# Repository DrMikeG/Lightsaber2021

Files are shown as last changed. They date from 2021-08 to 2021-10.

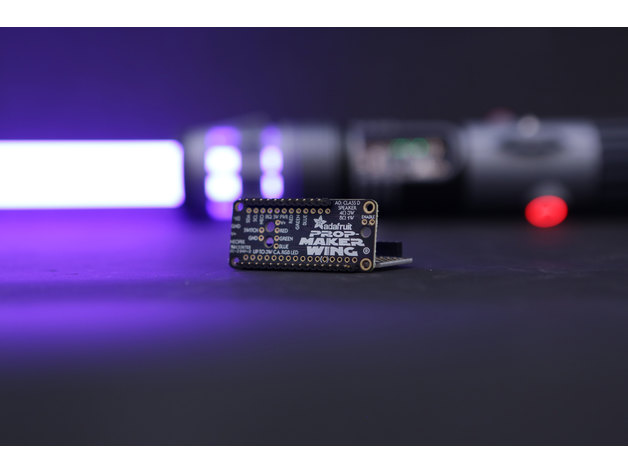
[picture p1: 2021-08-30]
PropMaker_LightSaber_parts/images/3bf46de2e516124390ac1d315bded442_preview_featured.jpg

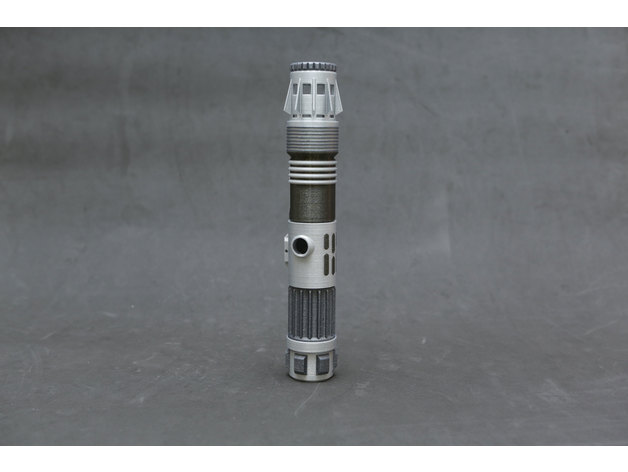
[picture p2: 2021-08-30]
PropMaker_LightSaber_parts/images/14ee97de2baf4f8e66ba40d05824f634_preview_featured.jpg

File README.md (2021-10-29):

# Lightsaber2021
Working on some light sabers with my kids

See: https://youtu.be/GwyaHJhU9TE

I'm using a Adafruit Feather M4 Express - Featuring ATSAMD51 (ATSAMD51 Cortex M4) × 1
which I am programming in circuit python using MU editor.
(You have to turn on the enable switch to get the feather to appear as a drive)
You don't have to turn it on to charge it.

https://learn.adafruit.com/adafruit-prop-maker-featherwing

https://learn.adafruit.com/lightsaber-featherwing

The PWR Pin
As mention above, the PWR pin is low (off) by default. To turn on power to the NeoPixels, Audio output, and RGB LED output, you must set this pin high (on).

You can check the pinout for your Feather to figure out which pin to use. But here's a quick reference for some of the boards:

Feather M0/M4 = D10
Feather 32u4 = D10
Feather 328 = D10
Feather NRF52 = D11
Feather ESP8266 = D15
Feather ESP32 = D33
And be sure to checkout the examples to see how this is done in code.

RGB LED version
https://learn.adafruit.com/prop-maker-light-wand

https://circuitpython.org/board/feather_m4_express/

https://learn.adafruit.com/adafruit-feather-m0-express-designed-for-circuit-python-circuitpython/adafruit2-pinouts

Putting a potentiometer onto an feather m4 express - via the feather prop wing.

The prop wing has breakouts for the express gpio pins, but which analog in pin can I use?

https://learn.adafruit.com/adafruit-prop-maker-featherwing/pinouts

I'm going to name the sides of the boards short and long.
One side of the feather has 16 pins (long) which include analog inputs.
The other side has 12 pins (mostly digital)

The longer side is the one I am interested in.

###Logic###
Only A0 is noted as being used.
```A0 - This pin is true analog input to the audio amplifier on the FeatherWing. Matches A0 on the Feather M0's and M4's which is the DAC output. Other Feathers (like the ESP8266) don't have a DAC so you can leave this pin unused```

###Power###
First two pins 
``Reset pin - Tie to ground to reset the Feather``
``3.3V pin- 3.3V output from the Feather's regulator``

A1 is located along the edge opposite the battery connector. There are multiple ground pins. 3V is located along the same edge as A1, and is next to the reset button.

```
"""CircuitPython Essentials Analog In example"""
import time
import board
from analogio import AnalogIn

analog_in = AnalogIn(board.A1)

def get_voltage(pin):
    return (pin.value * 3.3) / 65536

while True:
    print((get_voltage(analog_in),))
    time.sleep(0.1)
```

![Alt text](./readme_imgs/circuitpython_FeatherM0ExpressPot_bb.jpg)

So, today I learned that the switching tying the enable and ground pins on the prop wing, is an off-on switch, not an on-off switch.

That is - switched closed is off, switch open is on.

So, I tied an switched potentiometer onto the pins, so that I could turn the device on - and adjust an input voltage.

However, because the switch on the wing is, to my mind, backwards - the wing is only on when the switch is off - when the potentiometer is at its lowest setting.

![Alt text](./readme_imgs/Push-Pull-Pots.jpg)

The switch is make/break between the middle lug (eg B) and A or C for the push or pull.

I want to wire B/C as normally closed for off.

Potentiometer
pin value ranges from 160 - 65520

## 2021/09/26 Turn off sound ##

https://www.geeksforgeeks.org/time-perf_counter-function-in-python/

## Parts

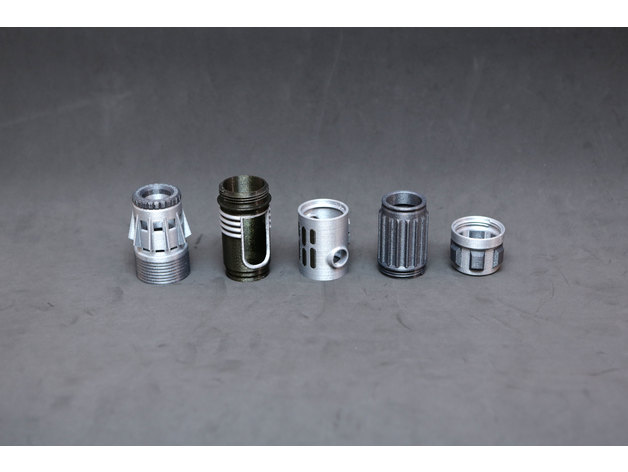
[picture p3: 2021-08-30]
PropMaker_LightSaber_parts/images/43d95a3ca8ac8f66d2d12bcbf307449e_preview_featured.jpg

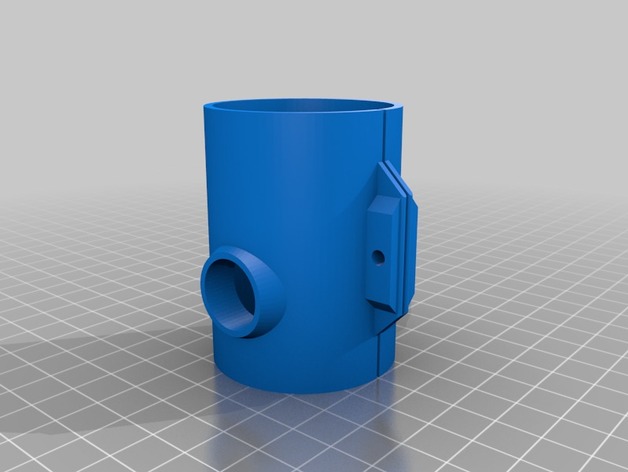
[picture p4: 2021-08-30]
PropMaker_LightSaber_parts/images/2298036a1407b53e1e762833e009448c_preview_featured.jpg

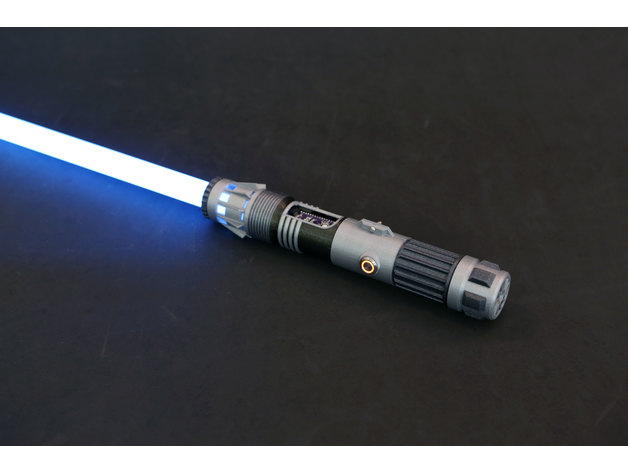
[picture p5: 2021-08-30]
PropMaker_LightSaber_parts/images/57906086d4f9e3c8136e70035f9d3a5d_preview_featured.jpg

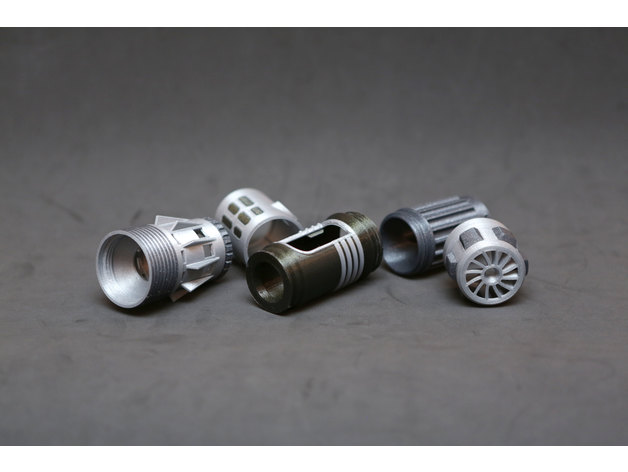
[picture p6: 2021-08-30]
PropMaker_LightSaber_parts/images/89f413c878babc25c42698dab03f24e1_preview_featured.jpg

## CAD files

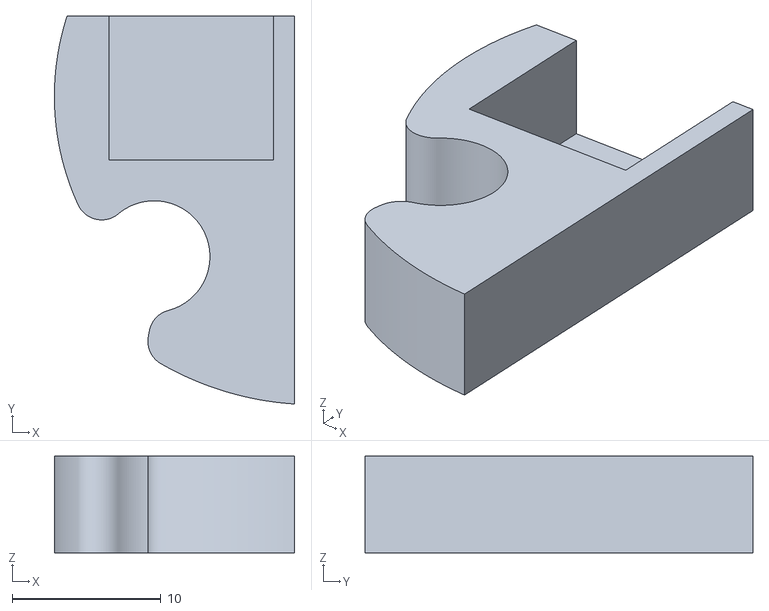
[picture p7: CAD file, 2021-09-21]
parts/UsbSupport01.stl
16.2 x 26.1 x 6.50

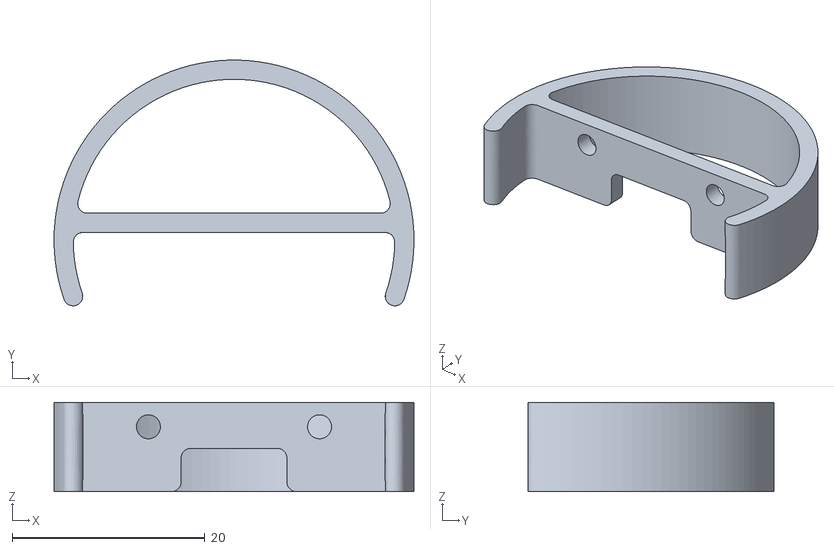
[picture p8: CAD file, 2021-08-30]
PropMaker_LightSaber_parts/files/fwls-feather-mount.stl
37.4 x 25.5 x 9.28

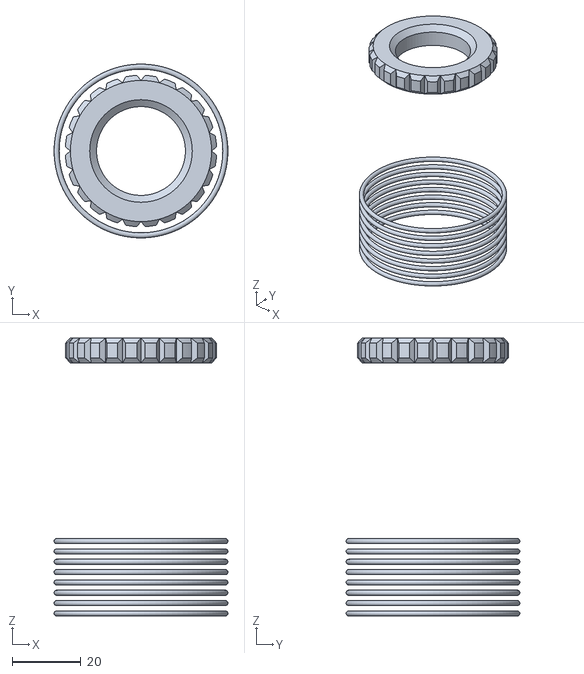
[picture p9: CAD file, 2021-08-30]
PropMaker_LightSaber_parts/files/multimats/fwls-emitter-b.stl
50.5 x 50.5 x 80.8

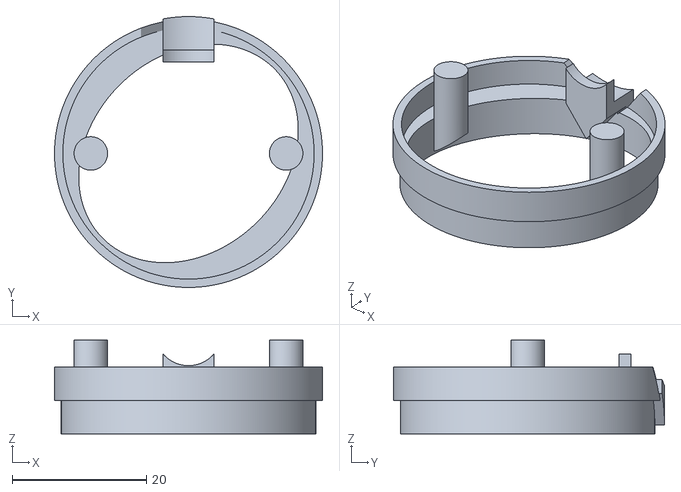
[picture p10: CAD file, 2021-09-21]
parts/BatteryHousing02.stl
40.0 x 40.4 x 14.0

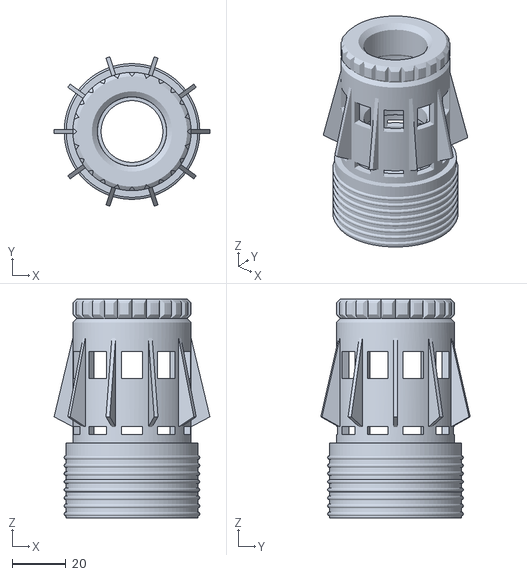
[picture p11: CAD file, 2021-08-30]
PropMaker_LightSaber_parts/files/fwls-emitter-single.stl
58.0 x 55.6 x 81.5

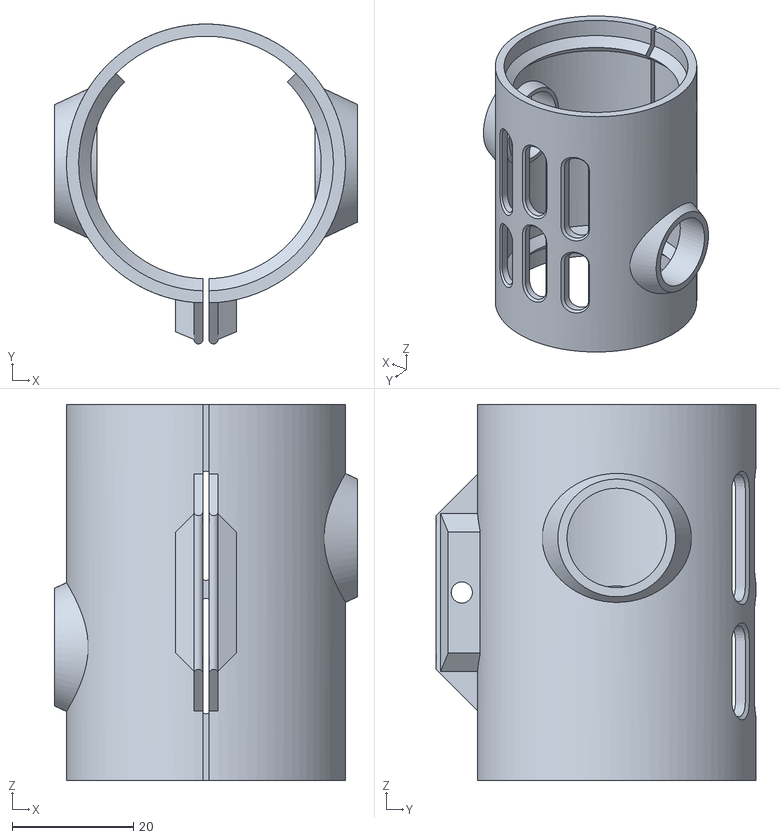
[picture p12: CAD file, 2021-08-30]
PropMaker_LightSaber_parts/files/multimats/fwls-clamp-a.stl
50.0 x 52.8 x 62.0

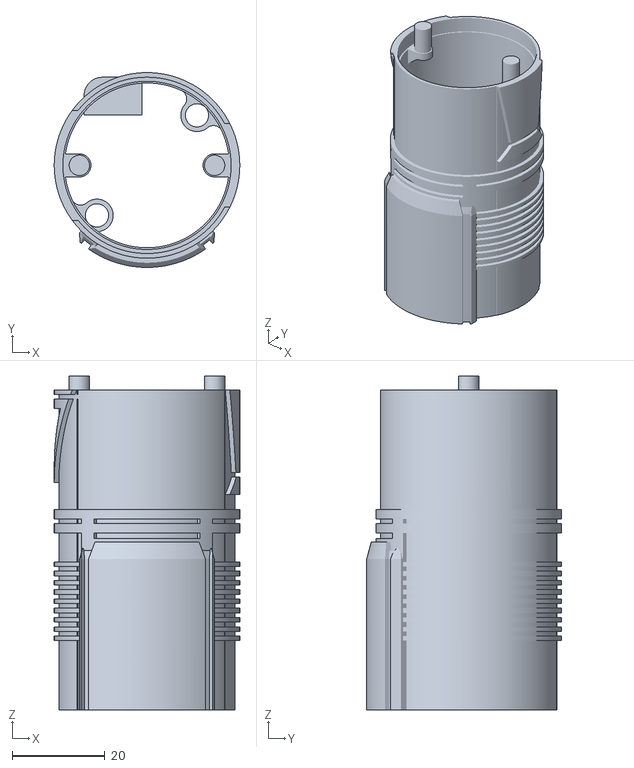
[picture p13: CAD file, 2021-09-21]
parts/FeatherHousing03.stl
40.0 x 42.0 x 72.0

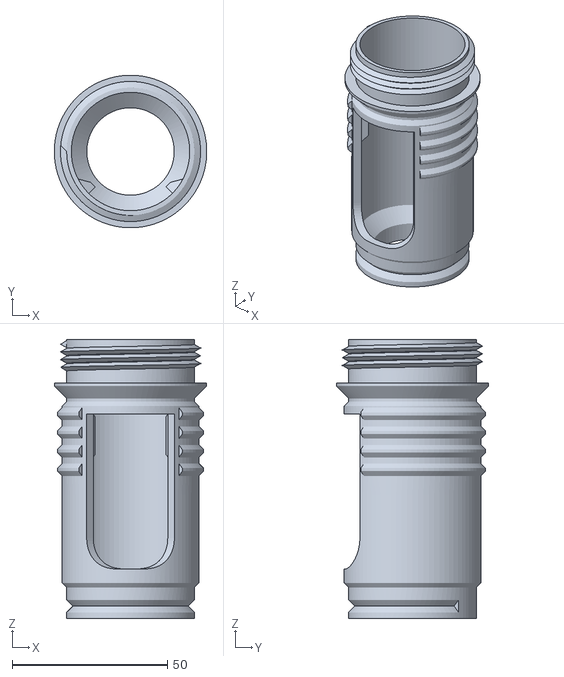
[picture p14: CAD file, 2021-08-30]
PropMaker_LightSaber_parts/files/fwls-barrel-single.stl
49.2 x 49.2 x 90.0

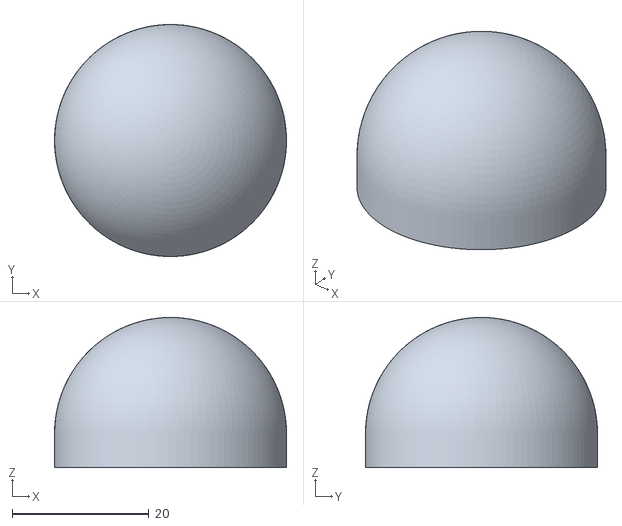
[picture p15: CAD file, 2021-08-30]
PropMaker_LightSaber_parts/files/fwls-blade-cap.stl
34.0 x 34.0 x 22.0

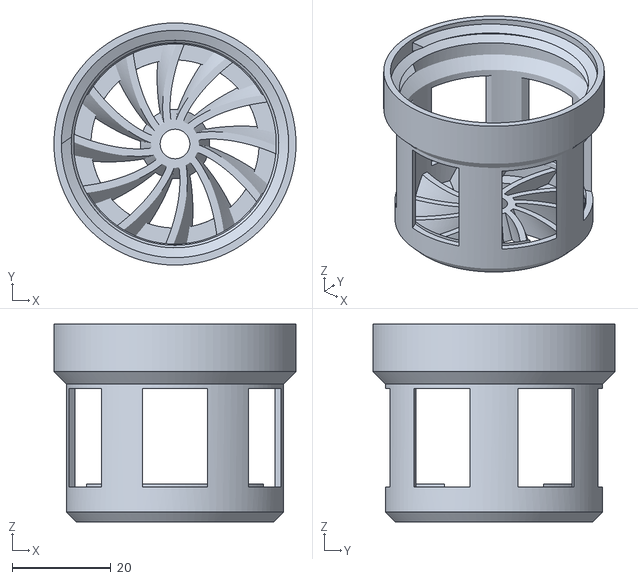
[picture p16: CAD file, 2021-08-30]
PropMaker_LightSaber_parts/files/multimats/fwls-pommel-a.stl
49.0 x 49.0 x 40.0

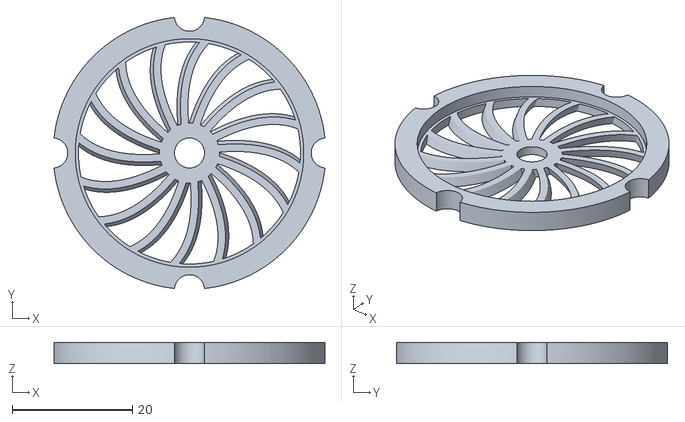
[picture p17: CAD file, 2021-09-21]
parts/SpeakerHousingBottomCover01.stl
45.1 x 45.1 x 3.50

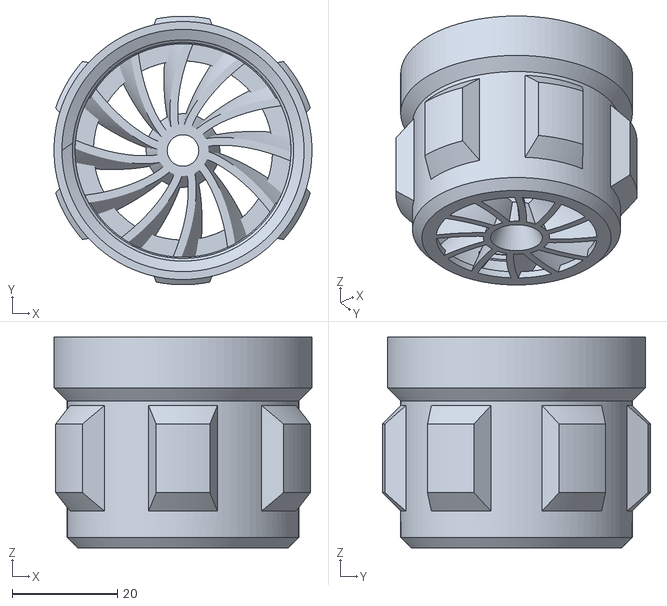
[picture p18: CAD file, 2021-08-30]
PropMaker_LightSaber_parts/files/fwls-pommel-single.stl
49.0 x 51.0 x 40.0

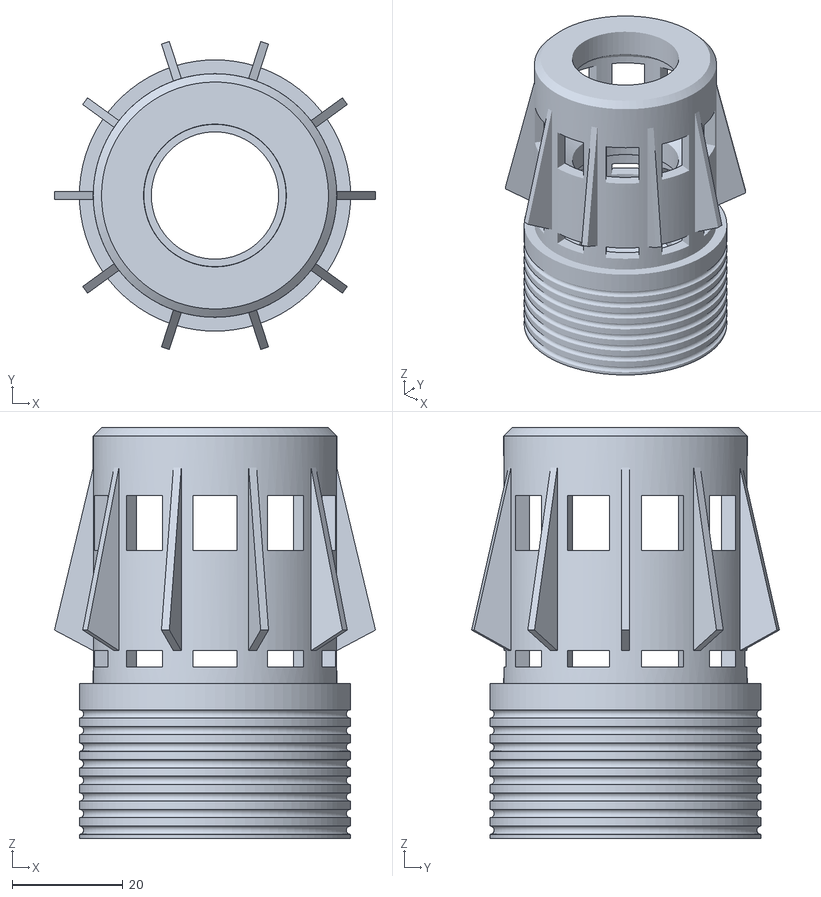
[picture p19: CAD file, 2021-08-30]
PropMaker_LightSaber_parts/files/multimats/fwls-emitter-a.stl
58.0 x 55.6 x 74.2

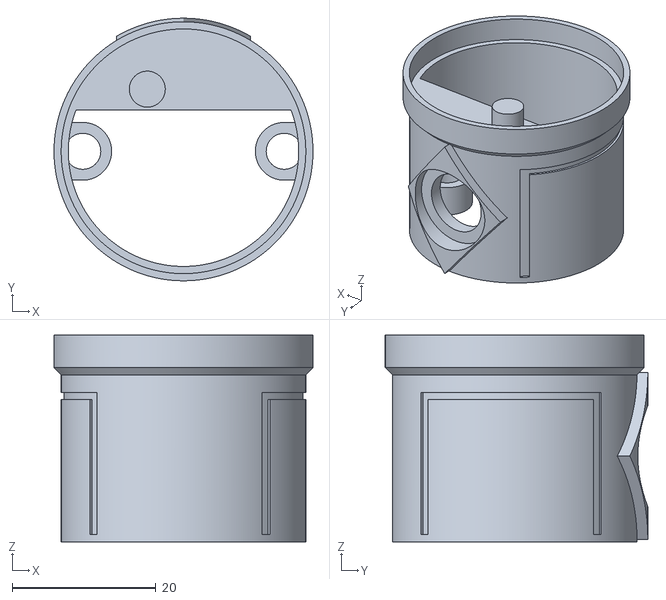
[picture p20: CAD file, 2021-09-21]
parts/SwitchHousing01.stl
36.0 x 36.5 x 28.7

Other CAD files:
PropMaker_LightSaber_parts/files/multimats/fwls-barrel-a.stl
parts/FeatherHousing02.stl
PropMaker_LightSaber_parts/files/fwls-clamp-single.stl
PropMaker_LightSaber_parts/files/multimats/fwls-pommel-b.stl
PropMaker_LightSaber_parts/files/fwls-powercell.stl
PropMaker_LightSaber_parts/files/fwls-wing-mount.stl
PropMaker_LightSaber_parts/files/multimats/fwls-barrel-b.stl
PropMaker_LightSaber_parts/files/multimats/fwls-clamp-b.stl
parts/BatteryHousing03.stl
parts/Helix02.stl
parts/Helix03.stl
parts/LedSupport01.stl
parts/LipoShell1.stl
parts/SpeakerHousing_01.stl
parts/SpeakerHousinga_01.stl
parts/SwitchHousing02.stl
parts/SwitchHousing03.stl

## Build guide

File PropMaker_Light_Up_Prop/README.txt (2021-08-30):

This bundle contains two folders, one each for CircuitPython 6.x and CircuitPython 7.x. You must use the files that match the version of CircuitPython you're using, e.g. if you are using CircuitPython 6, you will copy the files from the CircuitPython 6.x folder to your CIRCUITPY drive.

To use this project bundle, simply copy the contents of the CircuitPython version folder you're using from the zip file to your CIRCUITPY drive.
Contents in each version include:
* the code.py file
* the lib/ folder and all of its contents (including subfolders and .mpy or .py files)
* any assets (such as images, sounds, etc.)

NOTE: This will replace the current code.py, and the lib folder and its contents. Back up any desired code before copying these files!

 This zip was downloaded from https://learn.adafruit.com/prop-maker-light-wand/software on August 26, 2021.

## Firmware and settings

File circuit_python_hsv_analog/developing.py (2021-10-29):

"""
Prop-Maker based Light Up Prop.
Adafruit invests time and resources providing this open source code.
Please support Adafruit and open source hardware by purchasing
products from Adafruit!
Written by Kattni Rembor for Adafruit Industries
Copyright (c) 2019 Adafruit Industries
Licensed under the MIT license.
All text above must be included in any redistribution.
"""
import time
import random
import digitalio
import audioio
import audiocore
import busio
import board
import adafruit_rgbled
import adafruit_lis3dh
import math
from analogio import AnalogIn

# CUSTOMISE COLORS HERE:
MAIN_COLOR = (255, 0, 0)  # Default is red
HIT_COLOR = (255, 255, 255)  # Default is white

# CUSTOMISE SENSITIVITY HERE: smaller numbers = more sensitive to motion
HIT_THRESHOLD = 650
SWING_THRESHOLD = 125

# Set to the length in seconds of the "on.wav" file
POWER_ON_SOUND_DURATION = 1.5

POWER_PIN = board.D10

analog_in = AnalogIn(board.A1)

enable = digitalio.DigitalInOut(POWER_PIN)
enable.direction = digitalio.Direction.OUTPUT
enable.value = False

# Pin the Red LED is connected to
RED_LED = board.D11

# Pin the Green LED is connected to
GREEN_LED = board.D12

# Pin the Blue LED is connected to
BLUE_LED = board.D13

# Create the RGB LED object
led = adafruit_rgbled.RGBLED(RED_LED, GREEN_LED, BLUE_LED)

audio = audioio.AudioOut(board.A0)  # Speaker

# Set up accelerometer on I2C bus, 4G range:
i2c = busio.I2C(board.SCL, board.SDA)
accel = adafruit_lis3dh.LIS3DH_I2C(i2c)
accel.range = adafruit_lis3dh.RANGE_4_G

COLOR_HIT = HIT_COLOR  # "hit" color is HIT_COLOR set above
COLOR_SWING = MAIN_COLOR  # "swing" color is MAIN_COLOR set above

def hsv2rgb(h, s, v):

    """HSV to RGB

    :param float h: 0.0 - 360.0
    :param float s: 0.0 - 1.0
    :param float v: 0.0 - 1.0
    :return: rgb
    :rtype: list

    """

    c = v * s
    x = c * (1 - abs(((h/60.0) % 2) - 1))
    m = v - c

    rgb = [255,0,0]

    if 0.0 <= h < 60:
        rgb = (c, x, 0)
    elif 0.0 <= h < 120:
        rgb = (x, c, 0)
    elif 0.0 <= h < 180:
        rgb = (0, c, x)
    elif 0.0 <= h < 240:
        rgb = (0, x, c)
    elif 0.0 <= h < 300:
        rgb = (x, 0, c)
    elif 0.0 <= h < 360:
        rgb = (c, 0, x)

    return list(map(lambda n: (n + m) * 255, rgb))

def lerp0To360(inputValue):
    minInput = 150
    maxInput = 65520
    percent = inputValue/(maxInput-minInput)
    retVal = 360.0 * percent
    retVal = min(retVal,360.0)
    retVal = max(retVal,0.0)
    return retVal

def play_wav(name, loop=False):
    """
    Play a WAV file in the 'sounds' directory.
    :param name: partial file name string, complete name will be built around
                 this, e.g. passing 'foo' will play file 'sounds/foo.wav'.
    :param loop: if True, sound will repeat indefinitely (until interrupted
                 by another sound).
    """
    print("playing", name)
    try:
        wave_file = open('sounds/' + name + '.wav', 'rb')
        wave = audiocore.WaveFile(wave_file)
        audio.play(wave, loop=loop)
    except:  # pylint: disable=bare-except
        return


# List of swing wav files without the .wav in the name for use with play_wav()
swing_sounds = [
    'swing1',
    'swing2',
    'swing3',
    'swing4',
    'swing5',
    'swing6',
    'swing7',
    'swing8',
]

# List of hit wav files without the .wav in the name for use with play_wav()
hit_sounds = [
    'hit1',
    'hit2',
    'hit3',
    'hit4',
    'hit5',
    'hit6',
    'hit7',
    'hit8',
]

mode = 0  # Initial mode = OFF

soundOn = True
maxLerpSeen = False
minLerpSeen = False

# Main loop
while True:

    if mode == 0:  # If currently off...

        lerp = lerp0To360( analog_in.value )
        rgblist = hsv2rgb( lerp, 1.0, 0.8)
        MAIN_COLOR = (rgblist[0], rgblist[1], rgblist[2])  # Default is red

        enable.value = True

        play_wav('on')  # Power up!
        led.color = MAIN_COLOR
        time.sleep(POWER_ON_SOUND_DURATION)
        play_wav('idle', loop=True)  # Play idle sound now
        mode = 1  # Idle mode

    elif mode >= 1:  # If not OFF mode...
        x, y, z = accel.acceleration  # Read accelerometer
        accel_total = x * x + z * z
        # (Y axis isn't needed, due to the orientation that the Prop-Maker
        # Wing is mounted.  Also, square root isn't needed, since we're
        # comparing thresholds...use squared values instead.)
        #if accel_total > HIT_THRESHOLD:  # Large acceleration = HIT
        #    play_wav(random.choice(hit_sounds))  # Start playing 'hit' sound
        #    COLOR_ACTIVE = COLOR_HIT  # Set color to fade from
        #    mode = 3  # HIT mode

        # print()
        lerp = lerp0To360( analog_in.value )

        # max lerp is 360
        # min lerp is 5
        # if we have seen both 360 and 5 - toggle sounds.
        if lerp == 360 :
            maxLerpSeen = True
        elif lerp < 5 :
            minLerpSeen = True

        if maxLerpSeen and minLerpSeen:
            if soundOn:
                soundOn = False
                play_wav('off')
#                audio.stop()
            elif not soundOn:
                soundOn = True
                play_wav('idle', loop=True)  # Play idle sound now
            
            maxLerpSeen = False
            minLerpSeen = False

            print('toggle sound '+str(soundOn))
            

        rgblist = hsv2rgb( lerp, 1.0, 0.8)
        MAIN_COLOR = (rgblist[0], rgblist[1], rgblist[2])  # Default is red

        if soundOn:
            if mode == 1 and accel_total > SWING_THRESHOLD:  # Mild = SWING
                play_wav(random.choice(swing_sounds))  # Randomly choose from available swing sounds
                led.color = MAIN_COLOR  # Set color to main color
                mode = 2  # SWING mode
            elif mode == 1:
                # Idle color
                led.color = MAIN_COLOR
            elif mode > 1:  # If in SWING or HIT mode...
                if audio.playing:  # And sound currently playing...
                    if mode == 2:  # If SWING,
                        led.color = MAIN_COLOR
                    else:
                        led.color = HIT_COLOR  # Set color to hit color
                else:  # No sound now, but still SWING or HIT modes
                    play_wav('idle', loop=True)  # Resume idle sound
                    mode = 1  # Return to idle mode
        else:
            led.color = MAIN_COLOR

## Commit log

2021-08-30 Saving inital work before I start modifying the code in PropMaker_Light_Up_Prop to accept analog input.
    [Helix02.stl, Helix03.stl, LipoShell1.stl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]
2021-09-21 Saving all the parts and code I used to complete this project
    [Asm1.cfg, BatteryHousing02.stl, BatteryHousing03.stl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]
